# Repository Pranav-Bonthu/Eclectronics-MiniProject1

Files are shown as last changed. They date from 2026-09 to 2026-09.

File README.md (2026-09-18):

# Eclectronics Mini-Project 1
Final right up can be found here: ['docs/Electronics-Mini-Project-1.pdf'](docs/Electronics-Mini-Project-1.pdf)

<p align="center">
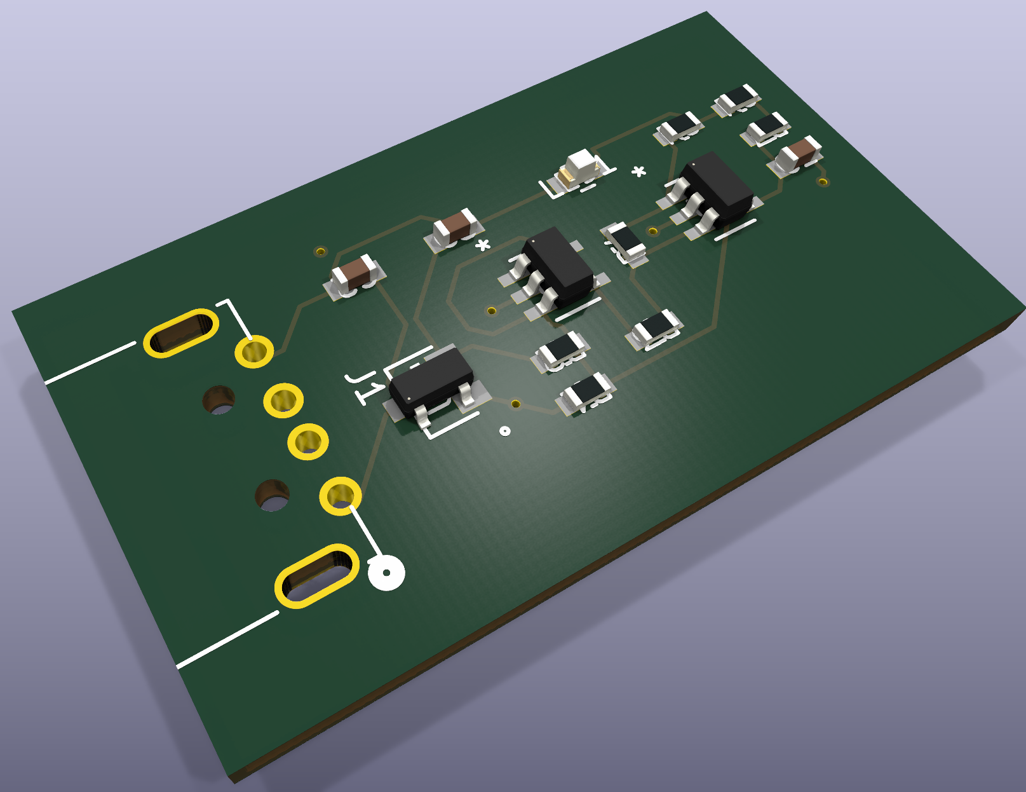
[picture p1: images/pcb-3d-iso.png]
3D render of the assembled board
  
</p>

---

## Simulation

<p align="center">
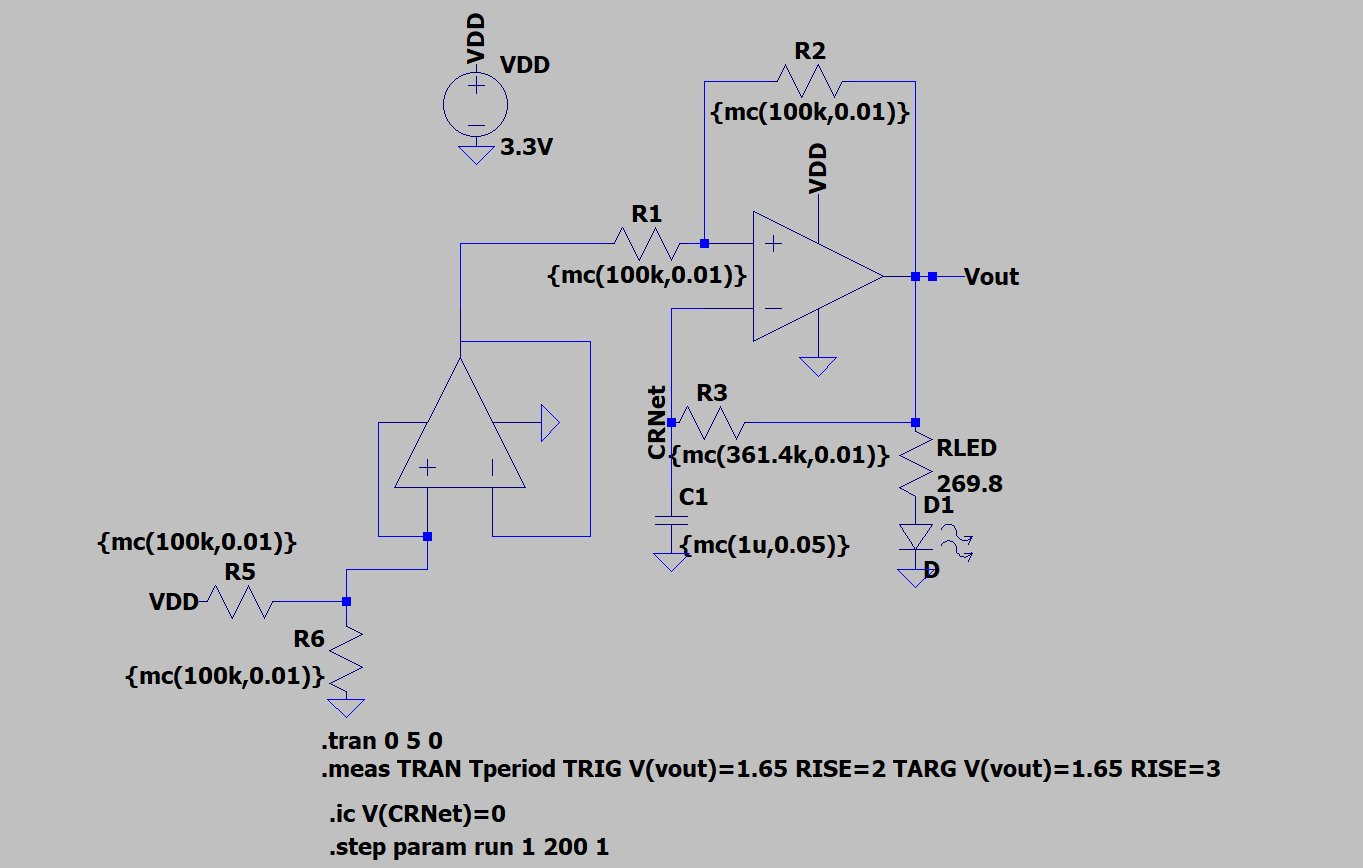
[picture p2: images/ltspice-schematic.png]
LTspice schematic
  
</p>

200-run Monte Carlo over 1 % resistor and 5 % capacitor tolerances:

<p align="center">
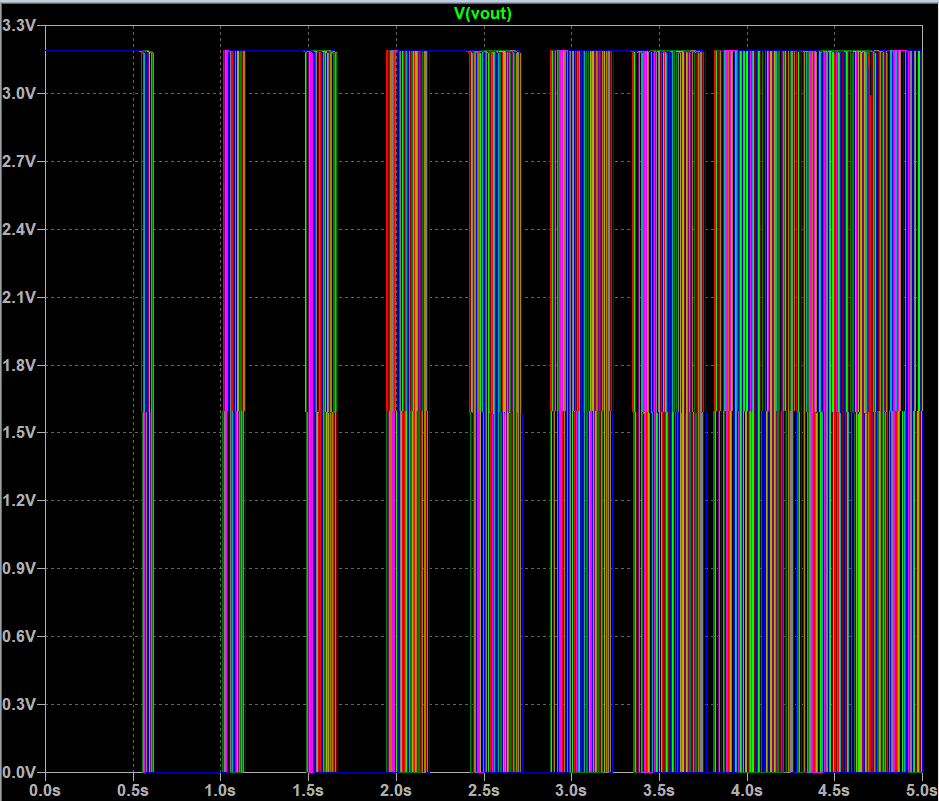
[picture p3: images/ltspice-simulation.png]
V(vout) across 200 Monte Carlo runs
  
</p>

---

## Schematic

<p align="center">
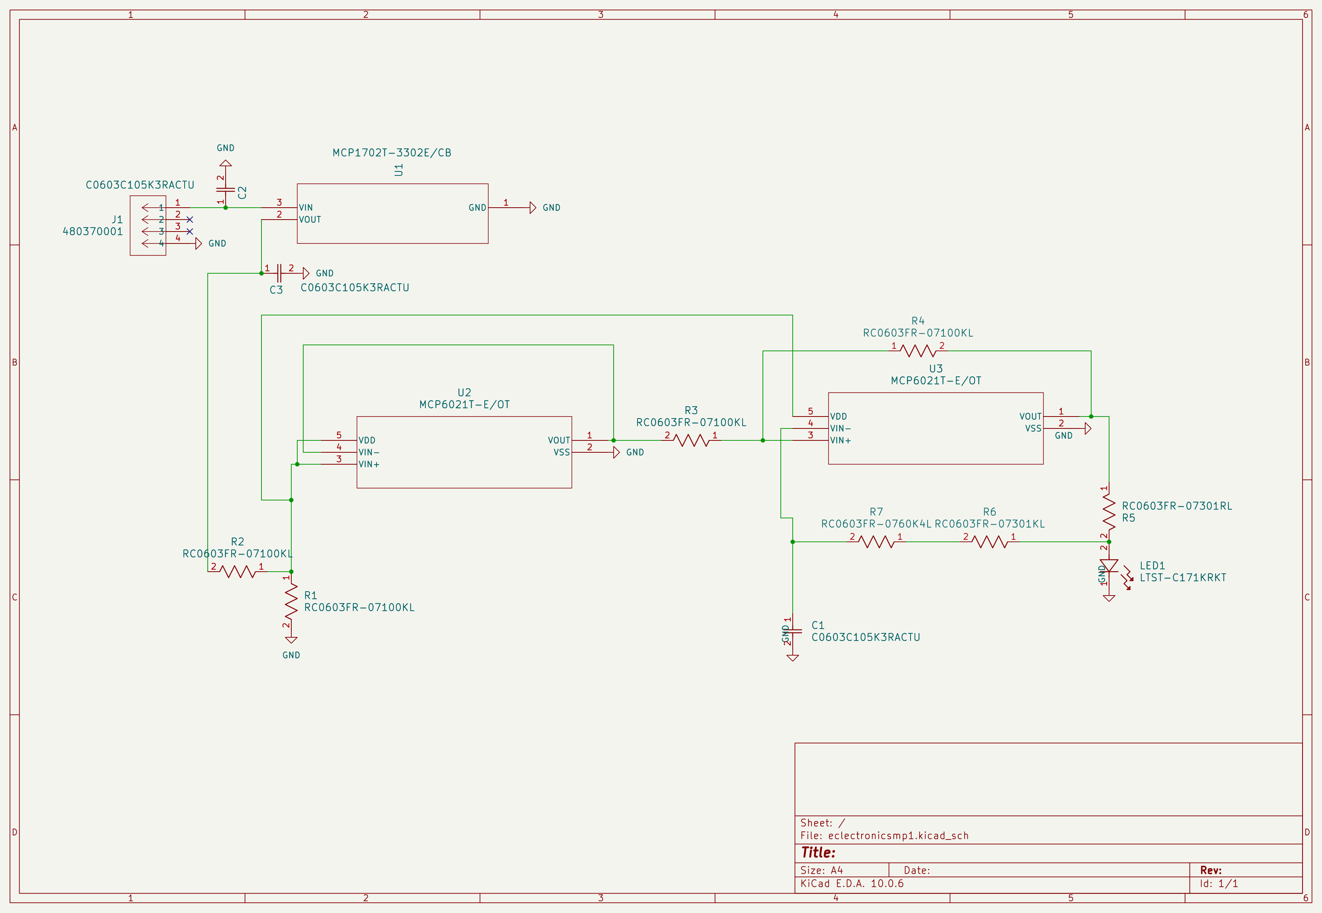
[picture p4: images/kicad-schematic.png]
KiCad schematic
  
</p>

PDF: [`docs/kicad-schematic.pdf`](docs/kicad-schematic.pdf)

---

## The board

| Top | Bottom |
|---|---|
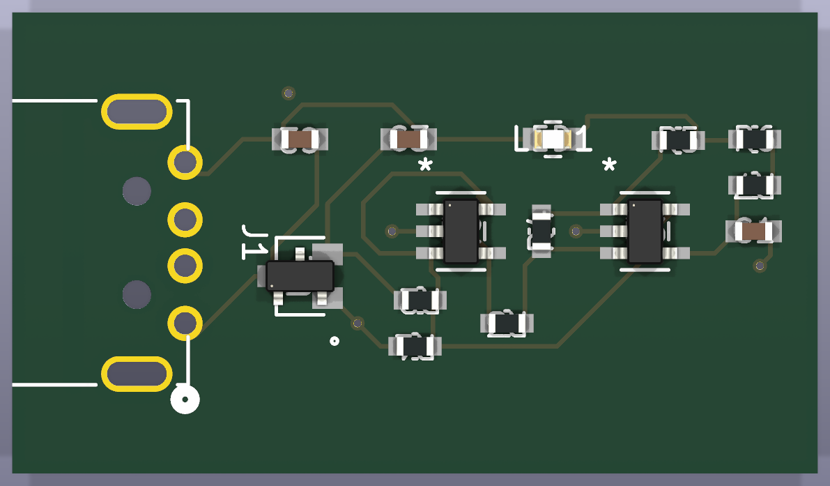
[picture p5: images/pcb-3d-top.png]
Top of the board
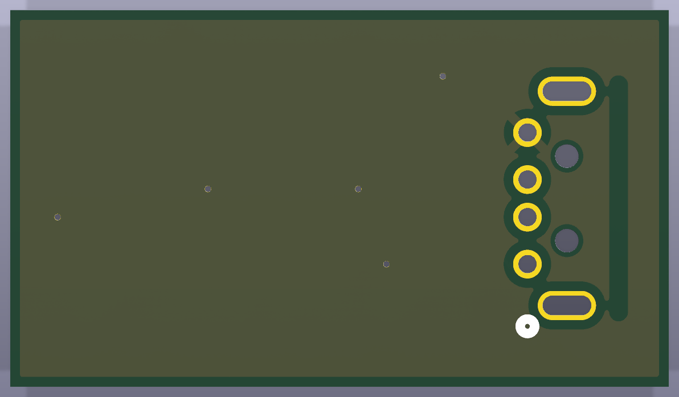
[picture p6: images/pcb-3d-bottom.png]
Bottom of the board
|  |  |

| Front (F.Cu ) | Back (B.Cu) |
|---|---|
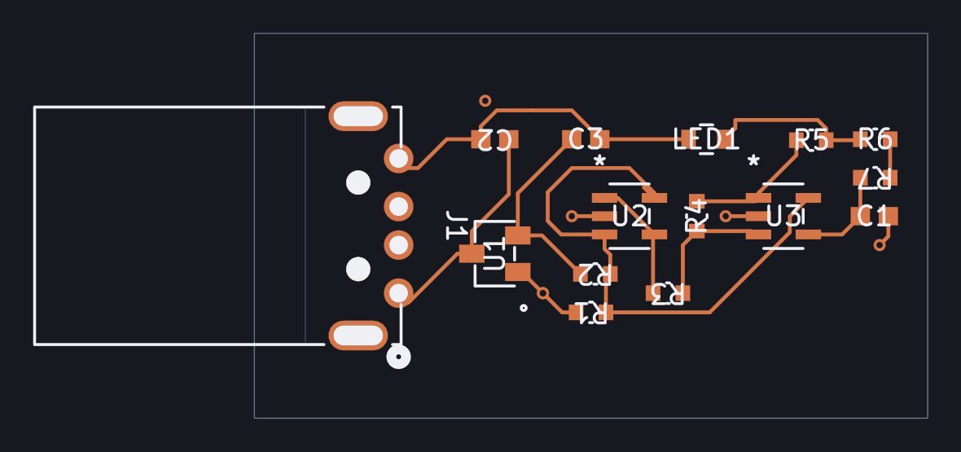
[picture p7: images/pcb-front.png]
Front copper and silkscreen
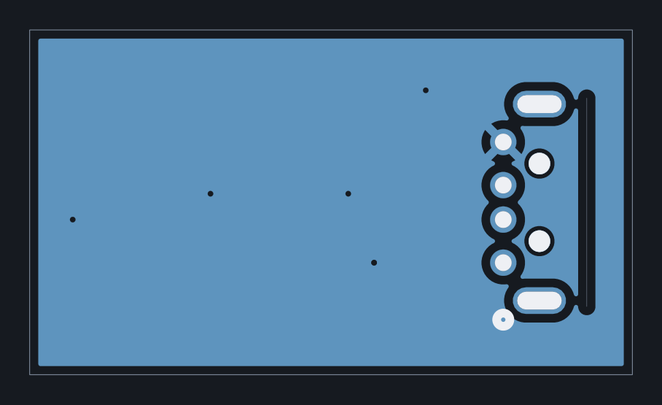
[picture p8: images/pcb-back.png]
Back copper
|  |  |

---

## Repository layout

```
kicad/        KiCad 10 project: schematic, board, and the
              symbol/footprint libraries it depends on
ltspice/      Simulation and results
fabrication/  Gerbers 
docs/         Project write-up and schematic PDF
images/       Images for the README    
```

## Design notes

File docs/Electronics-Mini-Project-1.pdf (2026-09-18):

# Electronics Mini-Project 1

Pranav Bonthu
09/16/2026

## 1. Introduction

The goal of this project is to design a circuit that flashes an LED within a period of 1 second, with a total tolerance of ± 10%.

The circuit I made includes a unity-gain buffer, establishing a reference that is half of the input voltage, which feeds into another op-amp. This second op-amp, alongside a resistor-capacitor circuit that feeds into the comparator, allows for the output of the op-amp to oscillate, causing the LED to flash on and off.

In order to complete this project, I designed an initial circuit in LTspice and performed Monte Carlo Simulations. Then, the schematic was remade within KiCad 10.0 and turned into a final PCB design.

## 2. Circuit architecture

The circuit divides into four stages: The USB 5V VBUS input, the voltage converter, the unity-gain buffer, and the comparator op-amp, which feeds into the flashing LED.

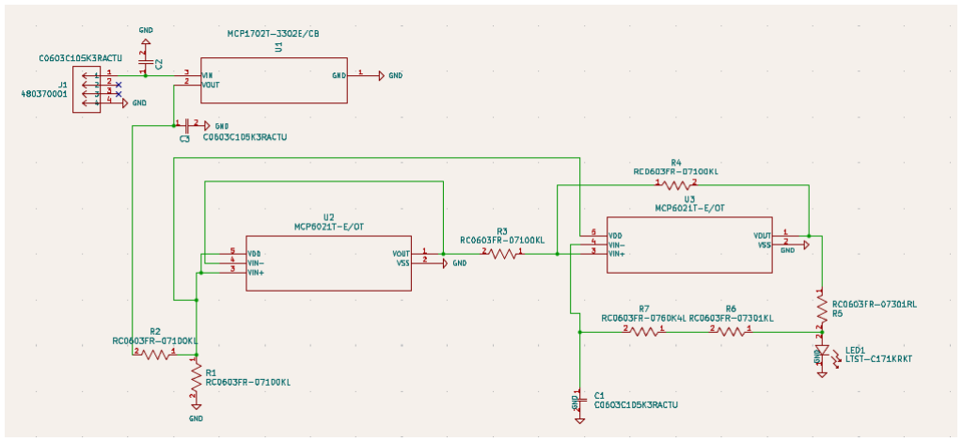
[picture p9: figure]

## 3. Power supply

The board draws power from USB VBUS and regulates it down to 3.3 V with an MCP1702T-3302E/CB low-dropout regulator (U1 in the KiCad schematic).

The USB Type_A plug has 4 pins: pin 1 for VBUS and pin 4 for GND. Pins 2 and 3 are data pins that are unused in this project.

The voltage regulator also makes use of bypass capacitors. In the datasheet of the component, it is required to have a capacitor between 1.0µF and 22µF. These capacitors allow for a smoother voltage output that is more robust to voltage spikes and drops.

It is important to note that in the LTspice model, this stage is omitted and is instead replaced by an ideal 3.3V power supply. This does not impact the simulation, as the oscillation is independent of the voltage.

## 4. Reference and buffer stage

Coming from the voltage regulator, the voltage of the buffer stage is roughly 3.3V, but this goes through a voltage divider (R5 and R6), both 100 kΩ, that inputs into the unity-gain buffer. The divider ratio is ½, so the input voltage into the unity-gain buffer is 3.3V/2 = ~1.65 V.

In this circuit, the buffer is necessary because an ideal buffer always reproduces its input voltage at its output, regardless of what's connected downstream. Without it, the reference node would connect directly to the oscillating comparator through R1. Because the comparator's output swings between the two rails as it oscillates, that connection would pull current from the reference divider in a way that varies with the oscillation, causing the reference voltage itself to shift over the cycle and changing the period along with it.

The reason this buffer is a unity-gain buffer is that the voltage must stay the same, and a unity-gain buffer has a gain of 1 (meaning the input is the same as the output).

## 5. Comparator Op-amp

U3, an op-amp in the schematics, and its surrounding components form the oscillator, which drives the flashing of the LED light. The derivation below produces the period equation that drives every component choice.

R1 runs from the buffered 1.65 V reference to U3's non-inverting input. R2 runs from that same node to the output. The node is therefore a two-resistor divider between Vref and Vout:

V+ = Vref · R2/(R1 + R2) + Vout · R1/(R1 + R2)

With R1 = R2 = 100 kΩ, this simplifies to the average of the two:

V+ = (Vref + Vout) / 2

Because the MCP6021 output is rail-to-rail, Vout is either VDD or 0. The threshold therefore takes two values:

Vout = VDD

V+ = (VDD/2 + VDD) / 2 = 3·VDD/4 = 2.475 V

Vout = 0 → V+ = (VDD/2 + 0) / 2 = VDD/4 = 0.825 V

The positive feedback through R2 means the switching threshold moves away from the capacitor voltage the instant the output flips, which sets the voltage window the capacitor must traverse.

R3 connects Vout to the capacitor node, and C1 connects that node to ground. The capacitor charges exponentially toward whatever the output currently is, with time constant:

τ = R3·C1.

U3's inverting input monitors this node, and because the op-amp input draws negligible current, R3 and C1 are the only elements that set the rate.

If the output were just switched high. The capacitor sits at the lower threshold VDD/4 and charges toward VDD. It rises until it reaches the upper threshold 3·VDD/4, at which point the inverting input exceeds the non-inverting input and the output switches low. Using the RC Charging equation for a first-order RC circuit

t_charge = R3·C1 · ln[(VDD − VDD/4) / (VDD − 3·VDD/4)] = R3·C1 · ln(3)

The output is now at 0, and the capacitor discharges toward 0 from 3·VDD/4 until it falls to VDD/4:

t_discharge = R3·C1 · ln[(3·VDD/4) / (VDD/4)] = R3·C1 · ln(3)

The two halves are equal, so the output is a symmetric square wave and the full period is:

T = 2 · R3 · C1 · ln(3) = 2.1972 · R3 · C1

It is important to notice that the VDD terms are dropped in the calculations, highlighting that the period is not dependent on voltage.

## 6. Component value selection

From Section 5, T = 2·R3·C1·ln(3). Setting T = 1.000 s:

R3·C1 = T / (2·ln 3) = 1.000 / 2.1972 = 0.4551 s

The period fixes only the product, so one value is free.

C1 = 1 µF. Chosen first, and chosen as this capacitor, as the tolerance is 5%, whereas capacitors higher in capacitance have a tolerance of 10%. This allowed the flashing of the circuit to remain within the tolerance

R3 = 361 kΩ.

Not an E96 value, so it is built as a series pair:

301 kΩ + 60.4k kΩ = 361.4 kΩ

R1 = R2 = 100 kΩ. Only the ratio matters. Equal values give:

V+ = (Vref + Vout)/2 → thresholds at VDD/4 = 0.825 V and 3·VDD/4 = 2.475 V

R5 = R6 = 100 kΩ. Sets Vref = VDD/2 exactly.

RLED = 301 Ω. With Vf = ~1.9 V for the LTST-C171KRKT:

I_LED = (VDD − Vf) / RLED = (3.3 − 1.9) / 301 = 4.65 mA

Well inside the MCP6021's ~30 mA output capability, so the output still reaches its rails.

## 7. LTspice simulation setup

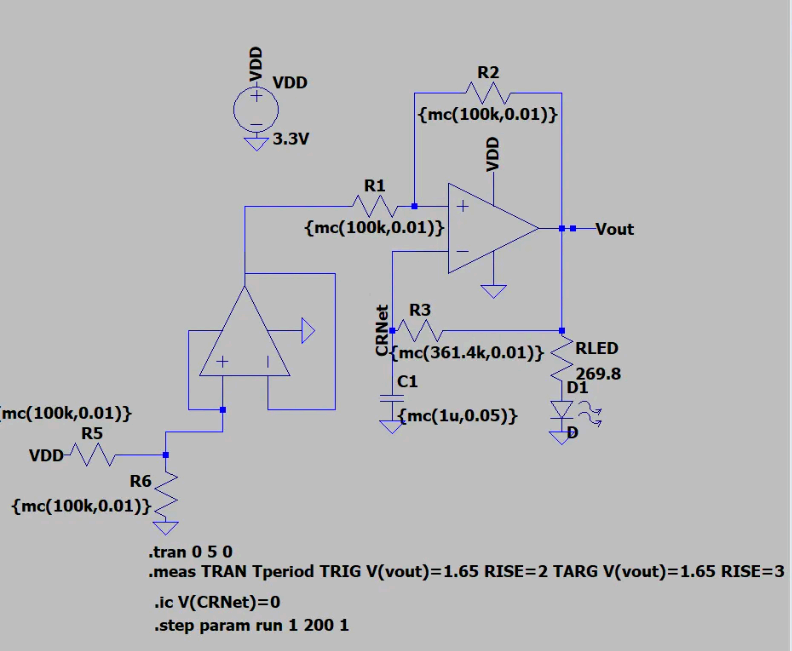
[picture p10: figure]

The LTspice model contains the reference divider, buffer, comparator, timing network, and LED branch, powered by an ideal 3.3 V source in place of the USB and regulator stage. Five directives control the simulation:

Directive | Function
.tran 0 5 0 | Runs a transient analysis from t = 0 to t = 5 s with no suppressed interval, capturing roughly five full oscillation cycles per run.

.ic V(CRNet)=0 Sets the initial condition on the capacitor node to 0 V. Without it the solver picks its own starting point, and the first half-cycle would be an arbitrary length that corrupts the period measurement.

.meas TRAN
Tperiod TRIG
V(vout)=1.65
RISE=1 TARG
V(vout)=1.65
RISE=2
| Measures the period automatically. It triggers on the first rising crossing of 1.65 V and targets the second, reporting the elapsed time.

.step param run 1
200 1

Sweeps a parameter from 1 to 200 in steps of 1, which executes the simulation 200 times.

{mc(nominal,
tol)}

Wraps every passive value. On each run it draws a value from a uniform distribution within tolerance.

## 8. Tolerance analysis

Monte Carlo Simulations:

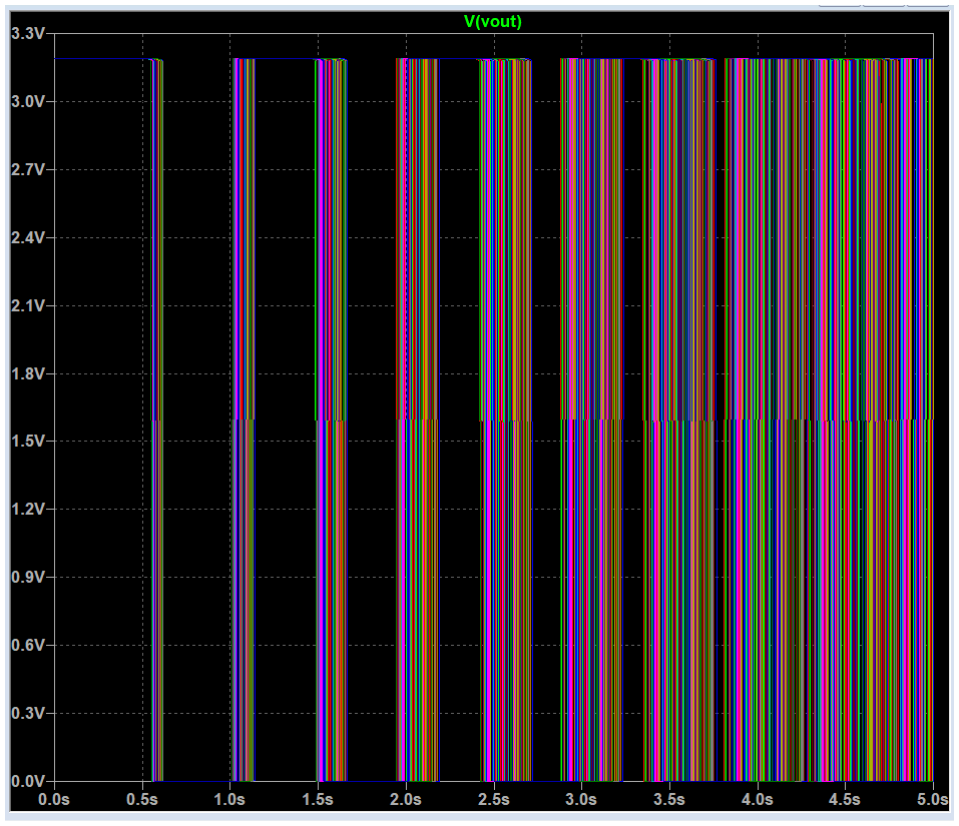
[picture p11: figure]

Results of VOut from 200 Monte Carlo Simulations, testing different tolerances of components

In each of the simulation results, the period landed within the range 0.9309 s to 1.0714 s, which fits the 10% tolerance.

## 9. PCB

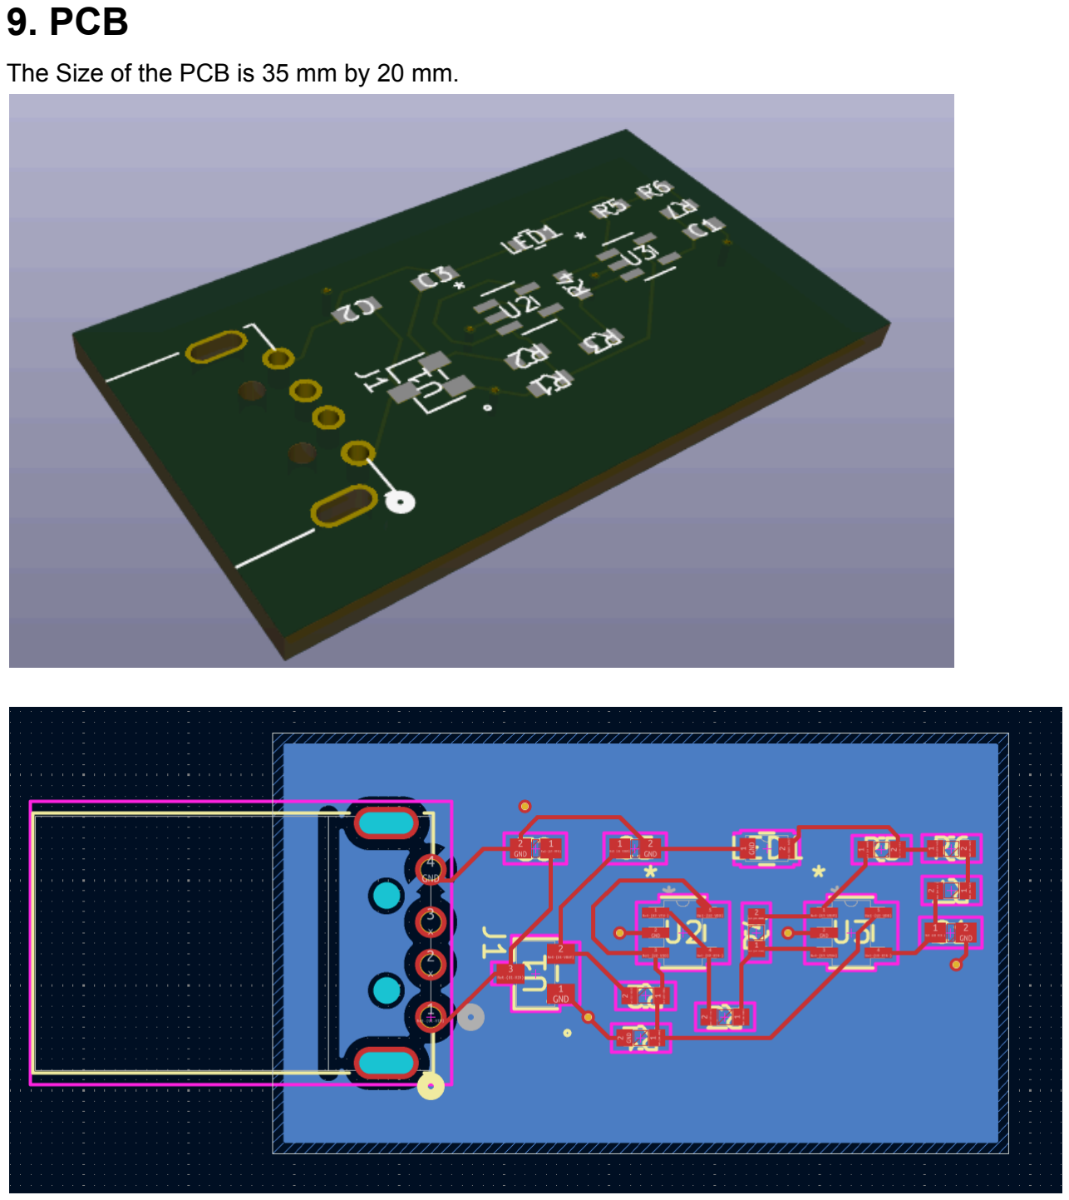
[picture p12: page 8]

The Size of the PCB is 35 mm by 20 mm.

## 10. Bill of materials

Qty | Value | Part number | Tolerance
1 | — | Molex 0480370001 | —
1 | 3.3 V | MCP1702T-3302E/C B

—

2 | — | MCP6021T-E/OT | —
3 | 1 µF | C0603C105K3RACT U

±5%

4 100 kΩ

RC0603FR-07100KL ±1%

1 301 kΩ

RC0603FR-07301KL ±1%

1 | Red | LTST-C171KRKT | —

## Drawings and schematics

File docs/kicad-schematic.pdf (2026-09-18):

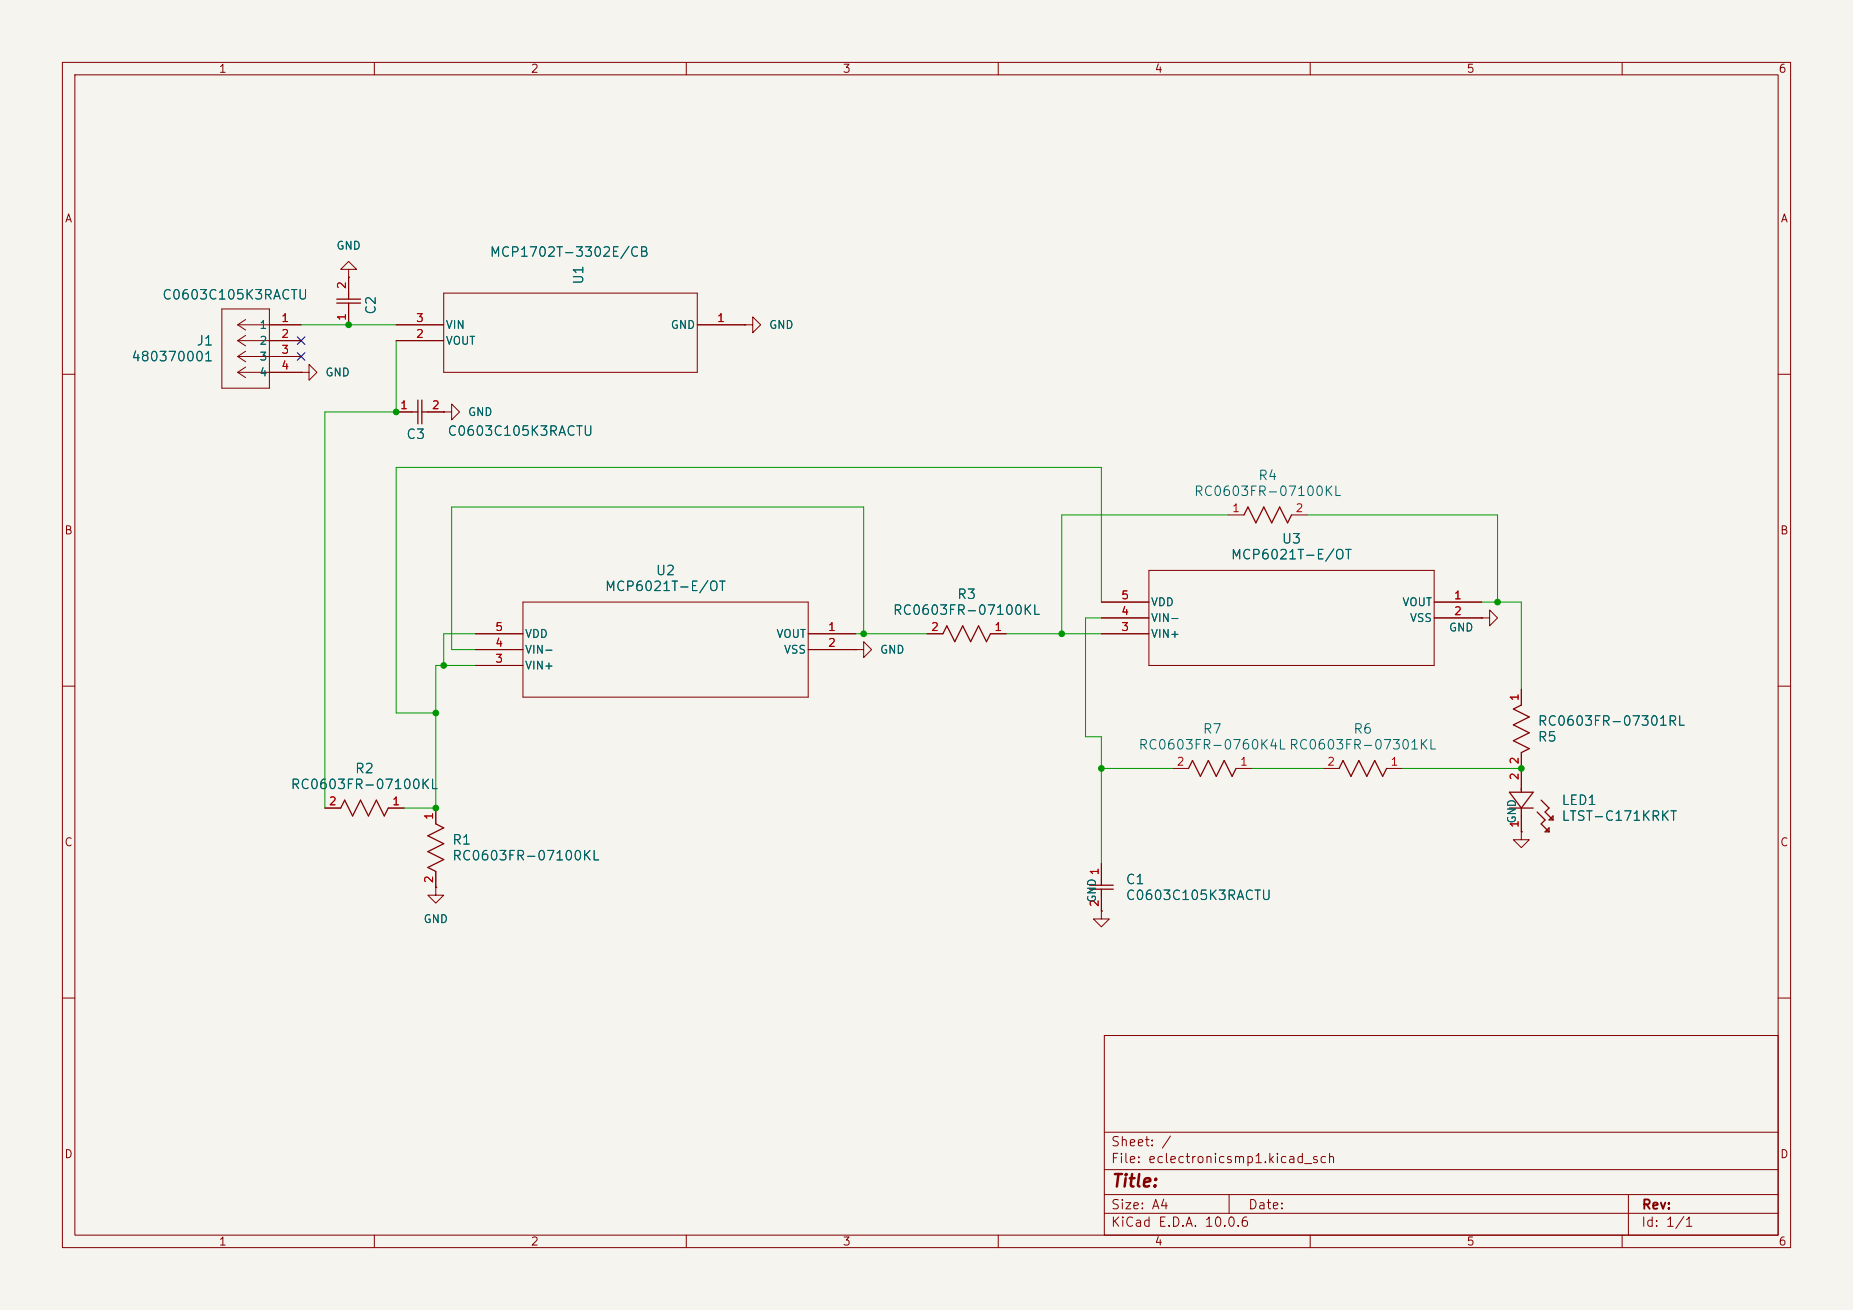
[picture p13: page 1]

Size: A4 | Rev:
KiCad E.D.A. 10.0.6 | Id: 1/1

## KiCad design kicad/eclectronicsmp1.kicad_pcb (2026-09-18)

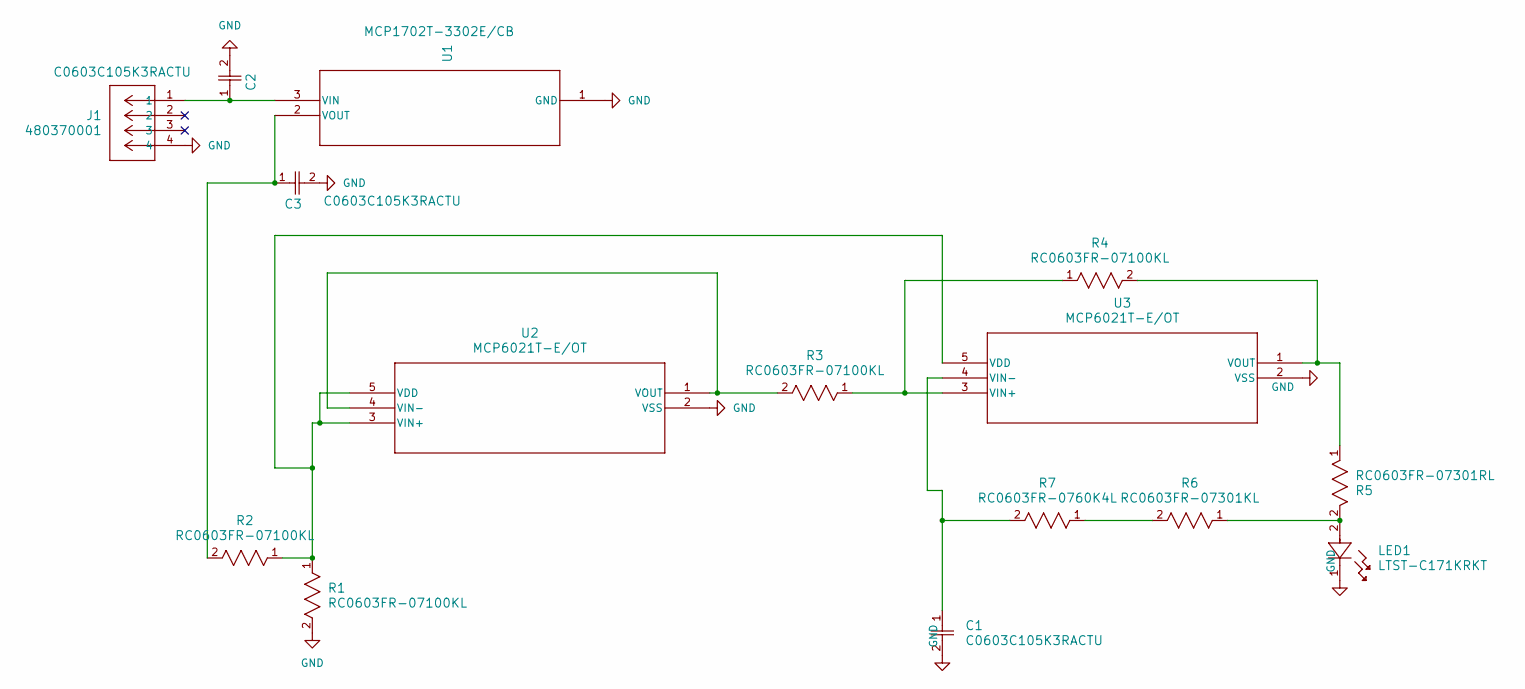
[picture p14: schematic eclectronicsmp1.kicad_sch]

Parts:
C1, C2, C3: C0603C105K3RACTU; CAPC17595_95N_KEM
J1: 480370001; CONN_480370001_MOL
LED1: LTST-C171KRKT; LED_LTST-C171_LTO
R1, R2, R3, R4: RC0603FR-07100KL; RC0603N_YAG
R5: RC0603FR-07301RL; RC0603N_YAG
R6: RC0603FR-07301KL; RC0603N_YAG
R7: RC0603FR-0760K4L; RC0603N_YAG
U1: MCP1702T-3302E/CB; SOT-23A_MC_MCH
U2, U3: MCP6021T-E/OT; SOT-23-5_MC_MCH

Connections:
GND: C1.2, C2.2, C3.2, J1.4, LED1.1, R1.2, U1.1 (GND), U2.2 (VSS), U3.2 (VSS)
unnamed: LED1.2, R5.2, R6.1
unnamed: R6.2, R7.1
unnamed: C2.1, J1.1, U1.3 (VIN)
unnamed: C3.1, R2.2, U1.2 (VOUT)
unnamed: R1.1, R2.1, U2.3 (VIN+), U2.5 (VDD), U3.5 (VDD)
unnamed: R3.2, U2.1 (VOUT), U2.4 (VIN-)
unnamed: R3.1, R4.1, U3.3 (VIN+)
unnamed: C1.1, R7.2, U3.4 (VIN-)
unnamed: R4.2, R5.1, U3.1 (VOUT)

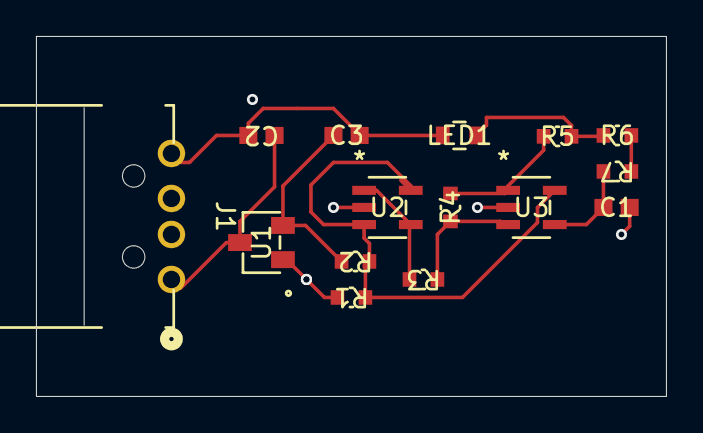
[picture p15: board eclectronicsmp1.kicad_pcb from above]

Board: 2 copper layers, 35.0 x 20.0 mm, 15 parts (0 on the bottom side), 10 nets.

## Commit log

2026-09-18 Organise repo into kicad/, ltspice/, fabrication/, docs/
    The repo held seven files flat at root with a 27-byte README. Sort them into
    directories by role and bring in the supporting files they need:
    - kicad/ board, schematic, project, plus the SnapEDA symbol/footprint
    libraries the design references through ${KIPRJMOD}. Without
    these the project does not open on another machine.
    - ltspice/ the final simulation deck, and the netlist + solver log from the
    200-run Monte Carlo that matches it byte-for-byte
    - fabrication/ Gerbers and a zipped fab package
    - docs/ project write-up and the schematic PDF
    Drop eclectronicsmp1.kicad_prl: i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
    [eclectronicsmp1-B_Cu.gbr, eclectronicsmp1-B_Mask.gbr, eclectronicsmp1-B_Paste.gbr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]
2026-09-18 Attach KiCad stock 3D models to the board footprints
    Every footprint in this design came from SnapEDA/DigiKey with no 3D model
    attached (grep -c '(model' returned 0), so `kicad-cli pcb render` produced a
    bare green board with nothing standing on it -- useless as a showcase image.
    All six packages are JEDEC-standard outlines, so KiCad's own shipped models fit
    without adjustment: 0603 for the resistors/caps/LED, SOT-23-5 for the op-amps,
    SOT-23 for the LDO. Referenced via ${KICAD10_3DMODEL_DIR} so the board stays
    portable. 14 of 15 components are now modelled.
    J1 is deliberately left bare. Its four signal pads use an irregular pitch
    (2.5/2.0/2.5 mm) that no stock Molex model matches, and a v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
    [eclectronicsmp1.kicad_pcb]
2026-09-18 Add tooling that generates every figure from the design files
    GitHub renders none of these formats -- .kicad_sch, .kicad_pcb, .asc and .raw
    all show as raw text or nothing -- so showcasing the board means generating
    images. Nothing in images/ is hand-made; tools/generate_assets.ps1 rebuilds all
    of it, so the README cannot drift from the design.
    - render_ltspice_asc.py LTspice has no headless image export at all, so this
    parses the .asc plus the .asy symbol definitions it
    references and redraws the schematic as SVG. The
    rotation mapping was verified against the schematic's
    own wire endpoints.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
2026-09-18 Add generated figures
    Schematic, PCB layer plots and 3D renders from kicad-cli; the LTspice schematic
    from the .asc renderer; Monte Carlo ensemble and period distribution from the
    solver log.
    Also commits ltspice/tperiod-montecarlo.csv -- the 200 measured periods pulled
    out of the log, so the headline result is readable on GitHub without opening
    LTspice.
    [tperiod-montecarlo.csv]
2026-09-18 Write the README as a showcase of the board
    Explains the relaxation oscillator, presents the Monte Carlo result (mean
    0.991 s, sigma 3.0 %, every one of the 200 builds oscillates), and shows the
    schematic, layer plots and 3D renders inline.
    Records the DRC/ERC findings rather than omitting them. The notable one is an
    error: J1's SnapEDA footprint carries its own rectangle on Edge.Cuts, so KiCad
    reports a malformed board outline. That needs fixing before the board is
    ordered.
2026-09-18 Trim the README to a visual showcase
    Drop the prose-heavy sections: how it works, the Monte Carlo write-up, the bill
    of materials, known issues, and the opening/regenerating/not-committed notes.
    What remains is the board itself -- hero render, schematic, top and bottom, the
    fabrication layer plots, and the repo layout. The LTspice schematic and the
    Monte Carlo figures stay in images/; they are simply no longer embedded here.
2026-09-18 Fix formatting in README.md for PCB images
2026-09-18 Remove the asset-generation tooling
    Takes tools/ out of the repo to keep it focused on the design itself. The
    figures in images/ are already committed, so the README is unaffected.
    Trade-off: the figures are no longer reproducible from the repo -- changing the
    schematic or board means redoing them by hand. The 3D models are already written
    into kicad/eclectronicsmp1.kicad_pcb, so the board keeps rendering with its
    components either way. The scripts remain in history at f4076a6 if they are ever
    needed again.
2026-09-18 Show the LTspice circuit and Monte Carlo results in the README
    Adds a Simulation section above the KiCad schematic: the LTspice circuit, the
    200-run ensemble of V(vout), and the blink-period distribution. All three images
    were already in images/ and simply unreferenced after the earlier trim.
2026-09-18 Use real LTspice screenshots for the Simulation section
    Replaces the generated figures with captures taken from LTspice itself: the
    schematic as drawn in the editor, and the 200-run V(vout) plot from the waveform
    viewer.
    Drops the generated ltspice-schematic.svg and the two matplotlib Monte Carlo
    figures, which these supersede. images/ now contains only images the README
    actually uses.
2026-09-18 Final touch up
    Removed the PDF link for the KiCad schematic.
